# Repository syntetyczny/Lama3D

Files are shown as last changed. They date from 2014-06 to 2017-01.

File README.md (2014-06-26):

Lama3D
======

Fullmetal hotend

Project and all files attached are licensed by Creative Commons license CC BY-SA 3.0 . If you want to comercially use project contact the author:
Paweł Janusz Dobrowolski
email: pawel.j.dobrowolski@gmail.com
company email: pjd@pjd-automatyka.pl

legal links:
http://creativecommons.org/licenses/by-sa/3.0/

http://creativecommons.org/licenses/by-sa/3.0/pl/legalcode

http://creativecommons.org/licenses/by-sa/3.0/pl/

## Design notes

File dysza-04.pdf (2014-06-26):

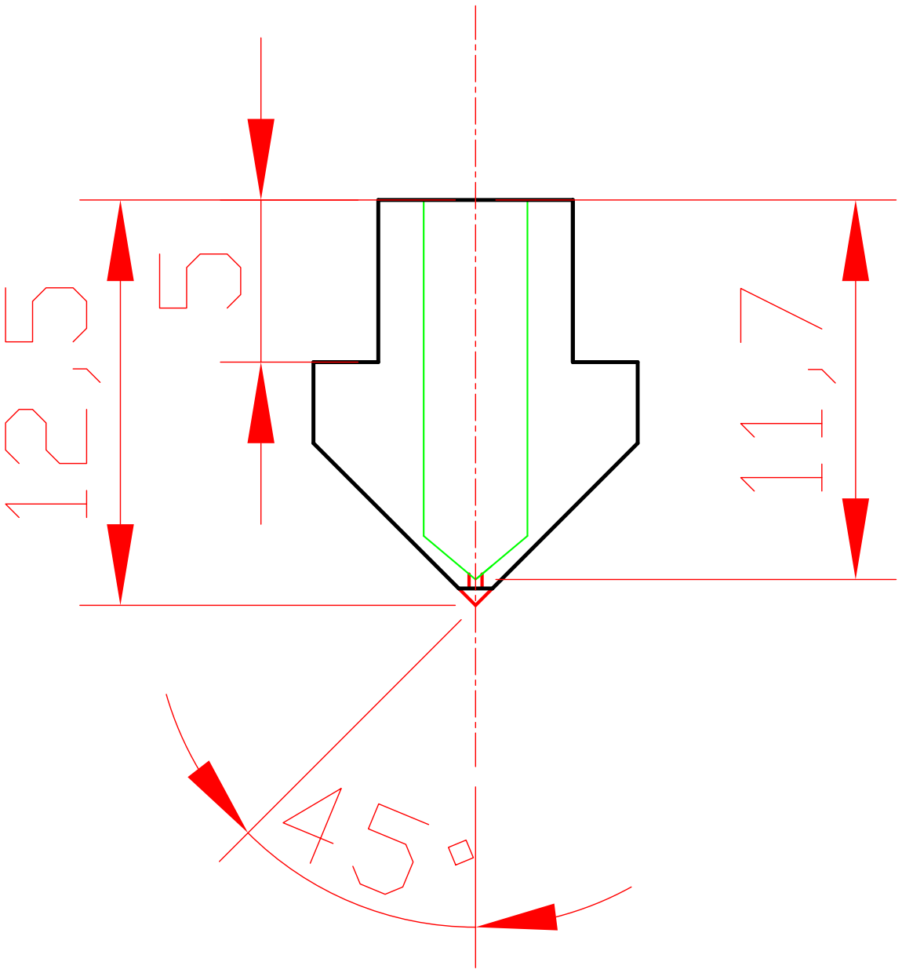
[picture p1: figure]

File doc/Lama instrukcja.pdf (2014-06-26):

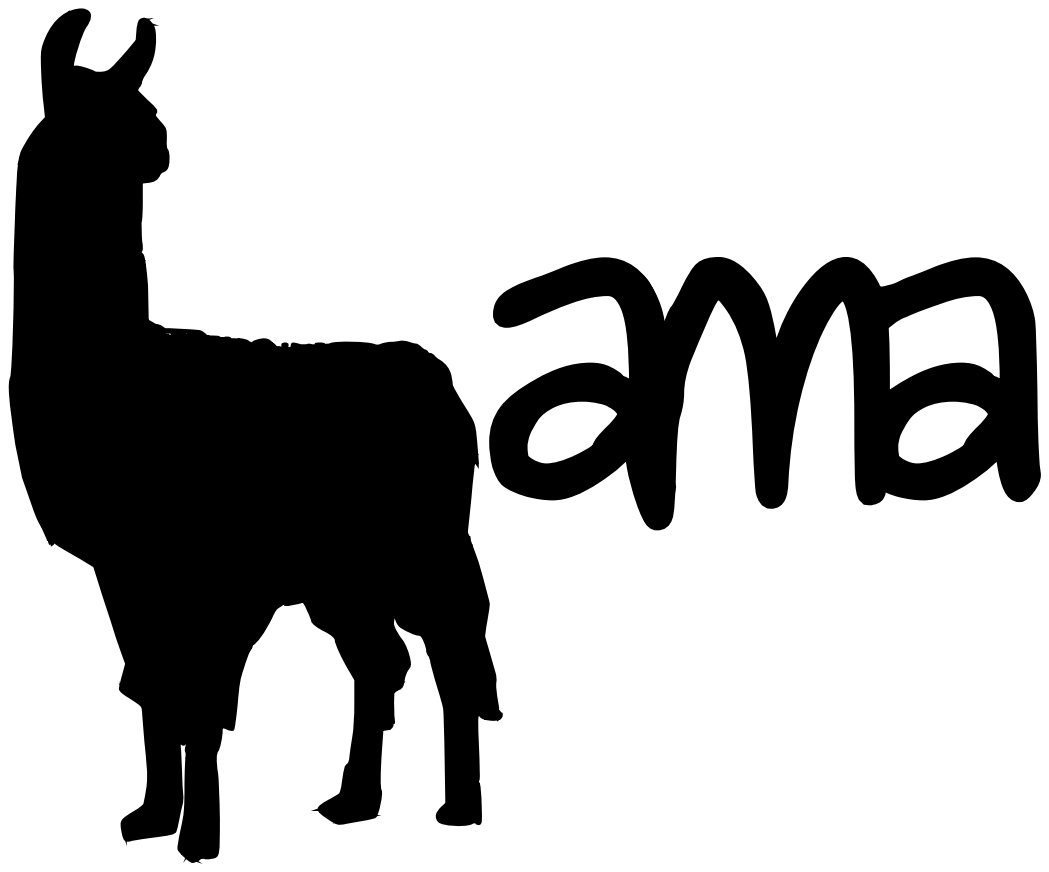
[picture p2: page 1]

Zestaw Lama3D zawiera:

- dyszę 0.4/0.5 mm
- stalowy łącznik nierdzewny
- aluminiowy blok grzejny
- aluminiowy radiator fi25
- Plastikowy uchwyt na wentylator
- Wentylator 40mm
- Koszulka silikonowo-szklana izolacyjna na termistor

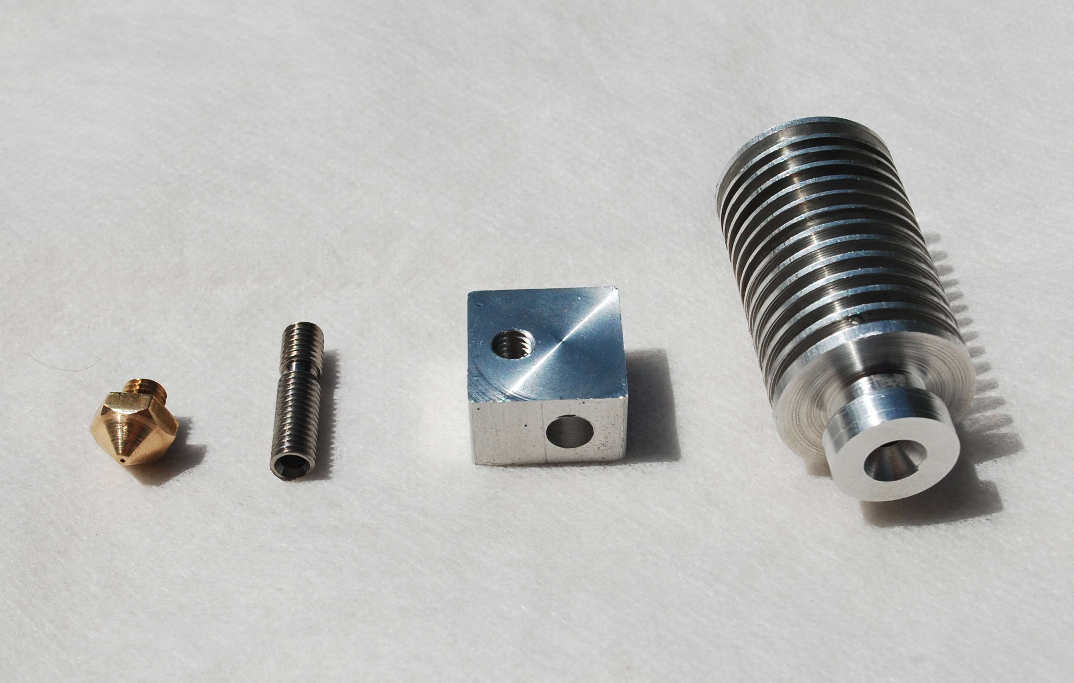
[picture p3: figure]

Dyszę wkręć w blok aluminiowy do napotkania oporu.

Łącznik stalowy wkręć z drugiej strony bloku.

Kiedy napotkasz opór odkręć o ¼ obrotu dyszę i dokręć łącznik do końca. Powinno to umożliwić późniejsze dokręcenie dyszy, w celu zapobiegnięcia wycieków.

Minimalny odstęp jaki powinien być widoczny pomiędzy dyszą a blokiem aluminiowym jest zaznaczony dużą zieloną strzałką.

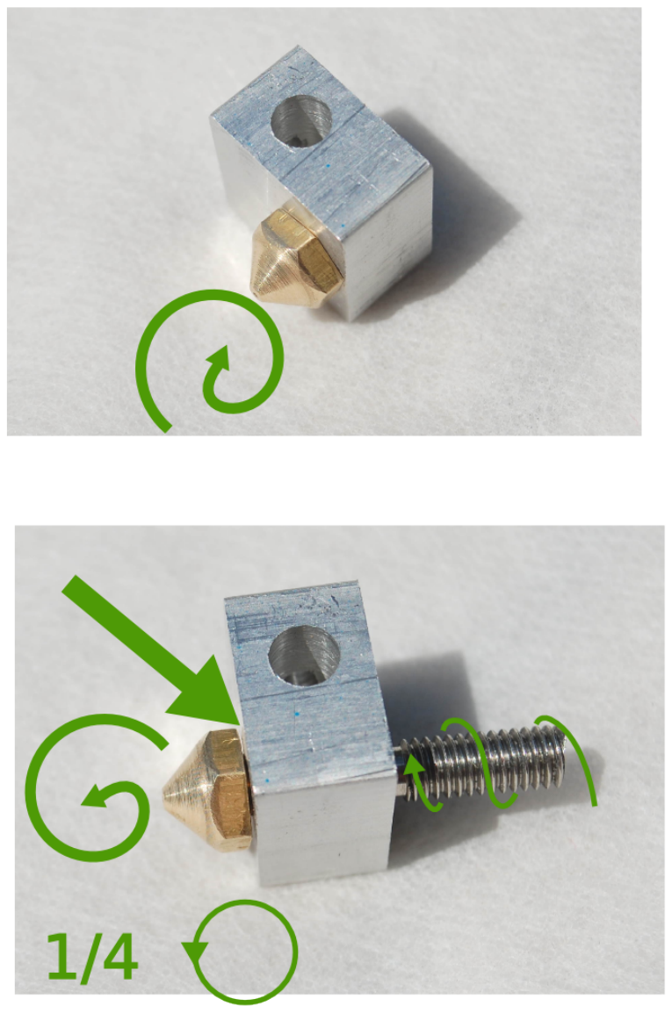
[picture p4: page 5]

Do całości dokręć teraz radiator tak aby odstęp pomiędzy nim a blokiem miał około 2mm.

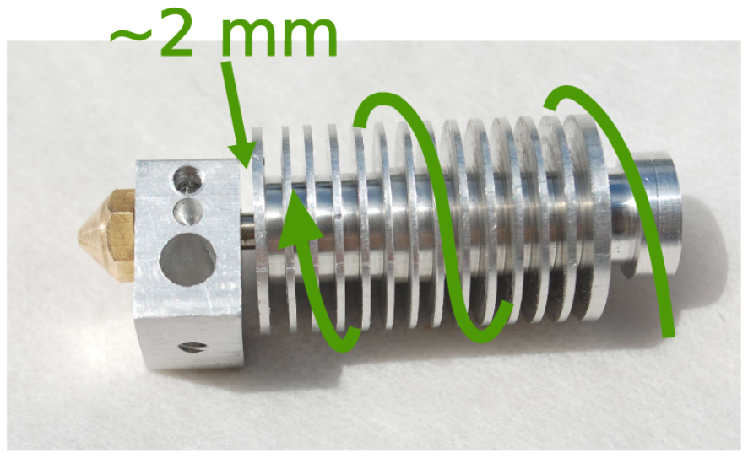
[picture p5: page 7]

Montaż termistora i grzałki

Nasuń osłonki na termistor jak pokazano na ilustracji.

Przygotuj:

- złożony zestaw dysza + radiator
- termistor w izolacji silikonowo-szklanej
- pastę termoprzewodzącą
- śrubkę M4L10 wraz z podkładką

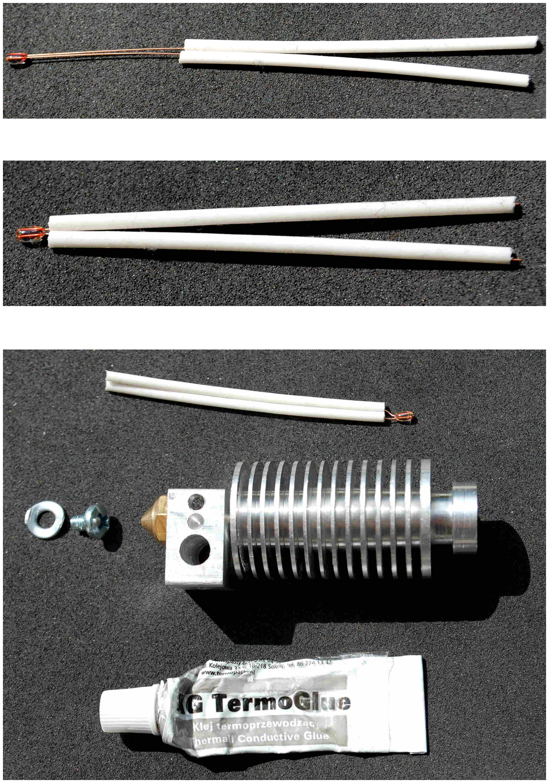
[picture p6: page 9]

Środkowy (niegwintowany) otwór na bloczku aluminiowym wypełnij pastą termoprzewodzącą po czym wsuń w niego termistor.

Dokręć całość śrubką M4L10 wraz z podkładką jak pokazano na ilustracji tym samym przymocowując termistor do bloku.

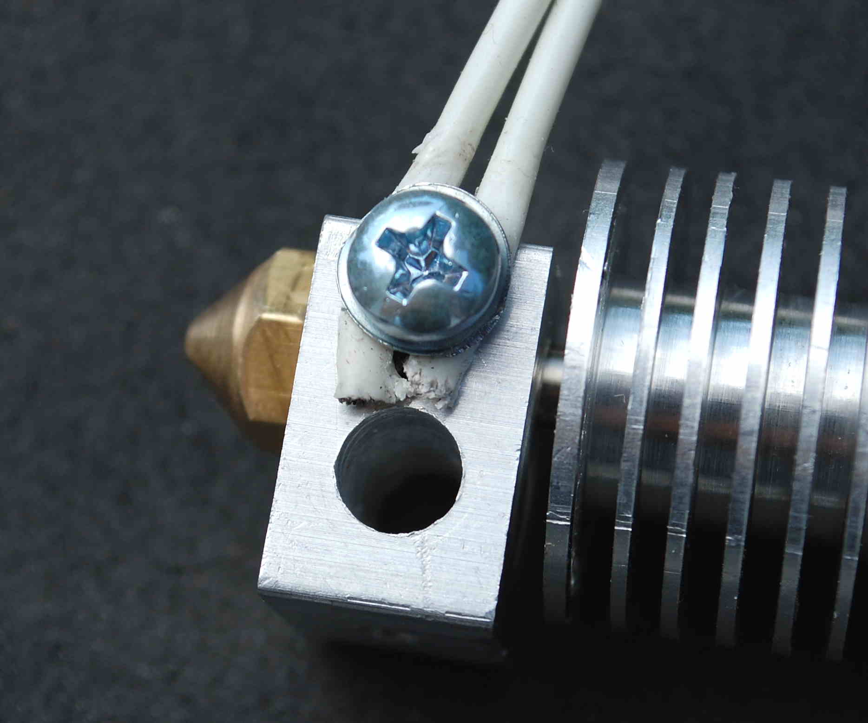
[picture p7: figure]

Przygotuj:
- elementy złożone w poprzednich krokach
- grzałkę
- śrubkę typu robaczek M4L4

Przełóż grzałkę przez najszerszy otwór w bloku po czym dokręć ją z boku robaczkiem M4L4.

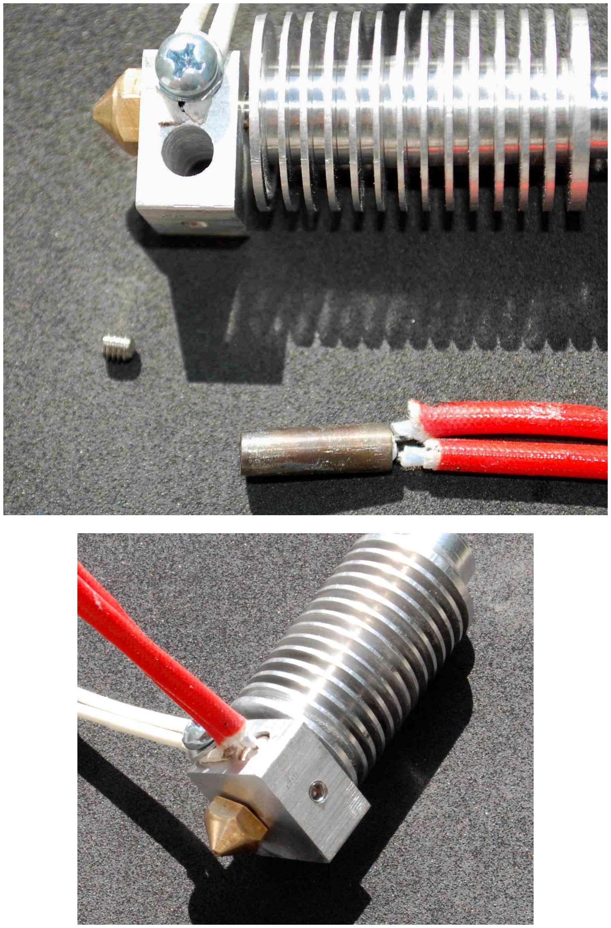
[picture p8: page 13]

Tak przygotowaną głowicę, montujemy do drukarki i nagrzewamy do temperatury 250st C. Następnie przygotowujemy 2 klucze płaskie -20(zamiast tego, może być użyty klucz uniwersalny) oraz 10. Kiedy głowica osiągnie 250st C, chwytamy kluczem 20 blok grzejny, oraz kluczem 10 dyszę i dokręcamy delikatnie dyszę do łącznika, aż poczujemy opór. Następnie używając już tylko klucza 10, dokręcamy całość do radiatora. Obie te operacje mają zapobiec wyciekowi roztopionego materiału na łączeniu dysza-łącznik oraz usunięcia luzu na połączeniu łącznik-radiator.

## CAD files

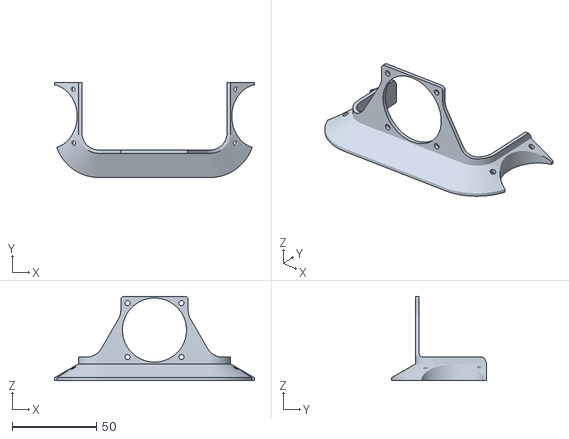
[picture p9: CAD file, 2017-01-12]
stl/BYQvent.stl
118.6 x 56.3 x 50.0

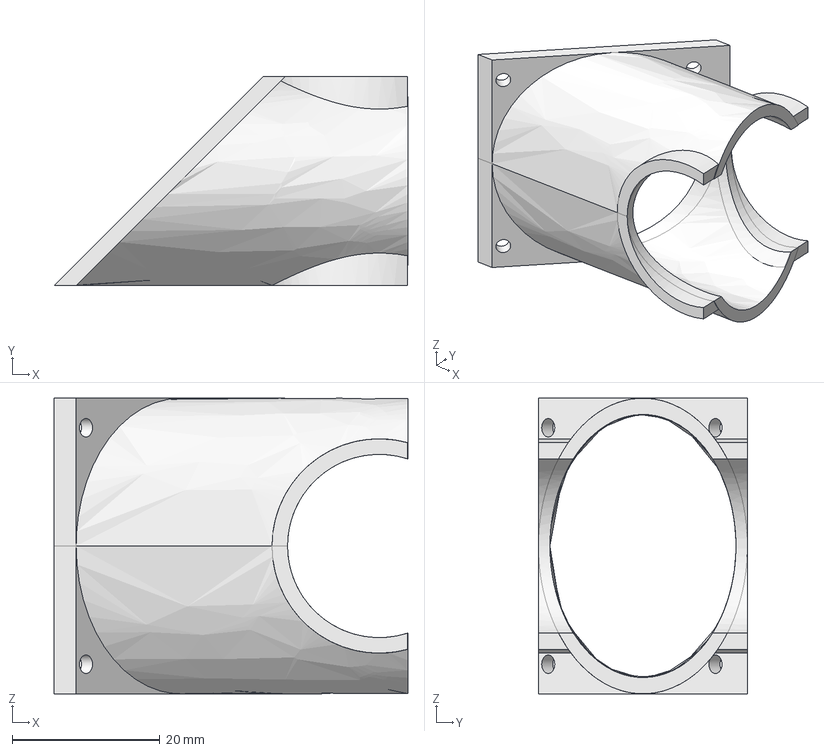
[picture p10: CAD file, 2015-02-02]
stl/uchwyt-wentylator-Mendel-thiner.fcstd
47.9 x 28.3 x 40.0 mm

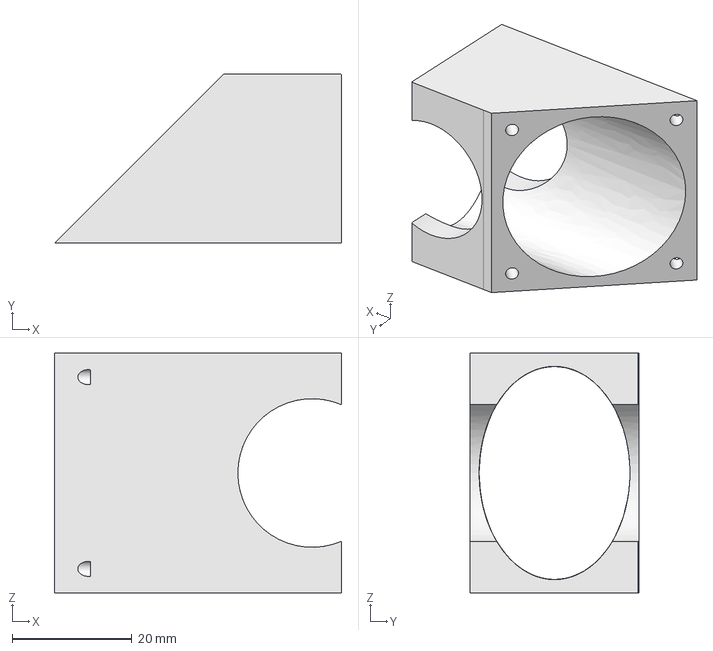
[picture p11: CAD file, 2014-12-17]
stl/uchwyt-wentylator-Mendel.fcstd
47.9 x 28.3 x 40.0 mm

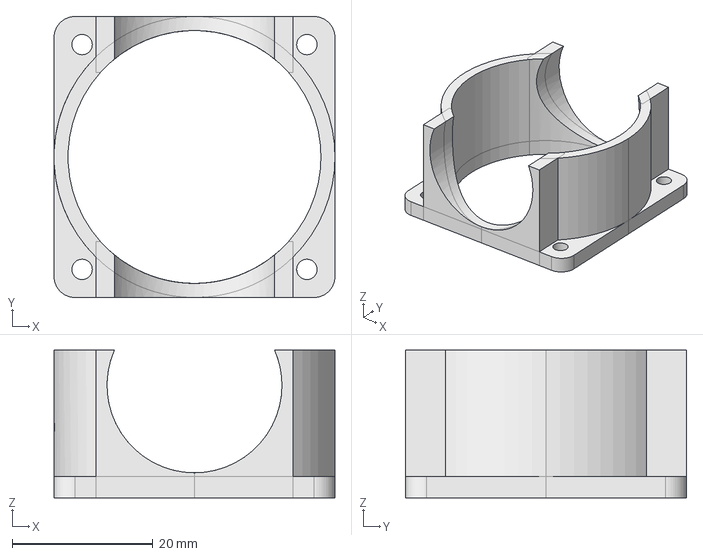
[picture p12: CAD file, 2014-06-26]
stl/wentyl v5 fi25.fcstd
40.0 x 40.0 x 21.0 mm

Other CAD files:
stl/uchwyt-wentylator-Mendel-thiner.stl
stl/uchwyt-wentylator-Mendel.stl
stl/wentyl v5 fi25.stl

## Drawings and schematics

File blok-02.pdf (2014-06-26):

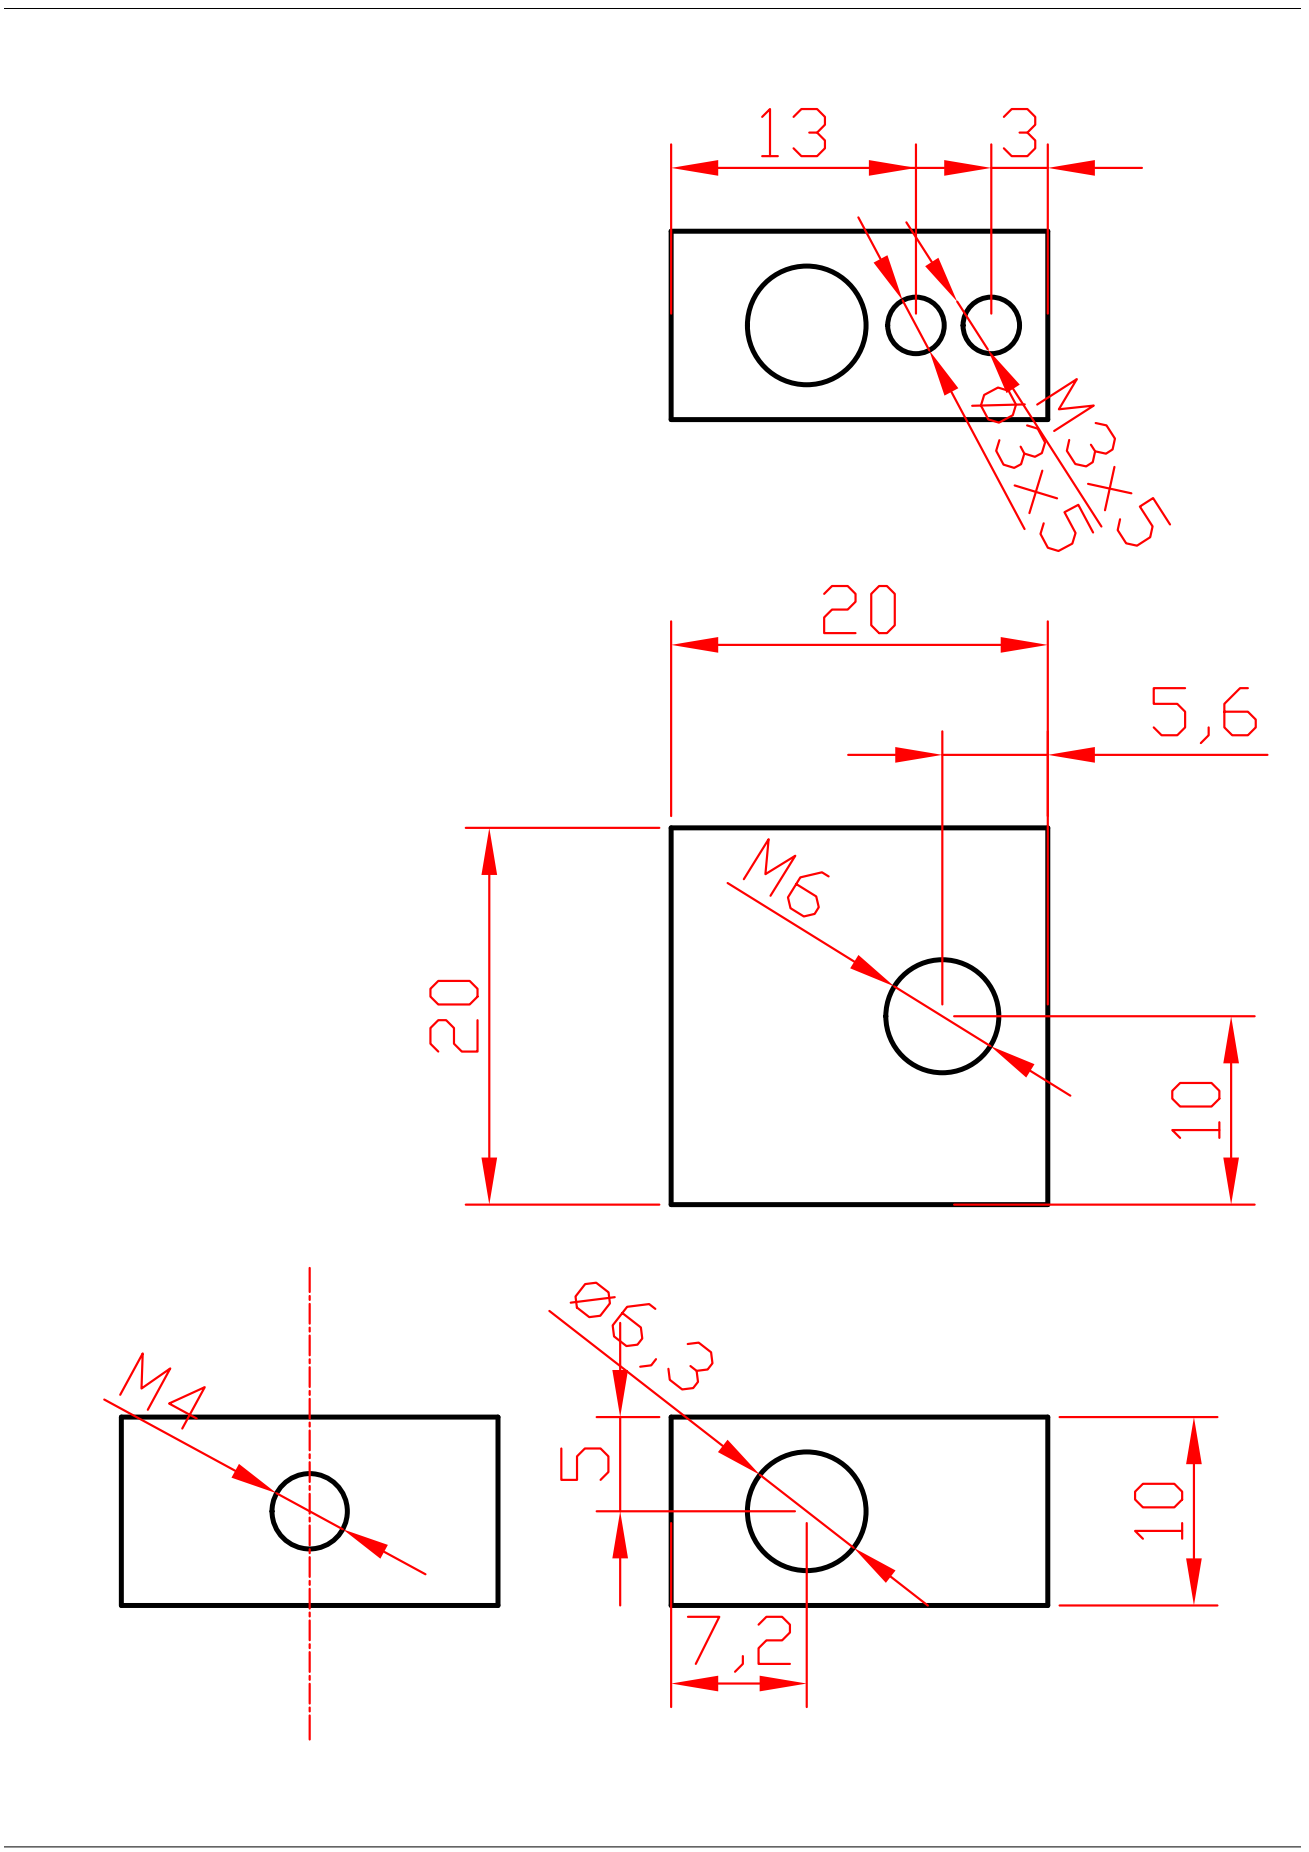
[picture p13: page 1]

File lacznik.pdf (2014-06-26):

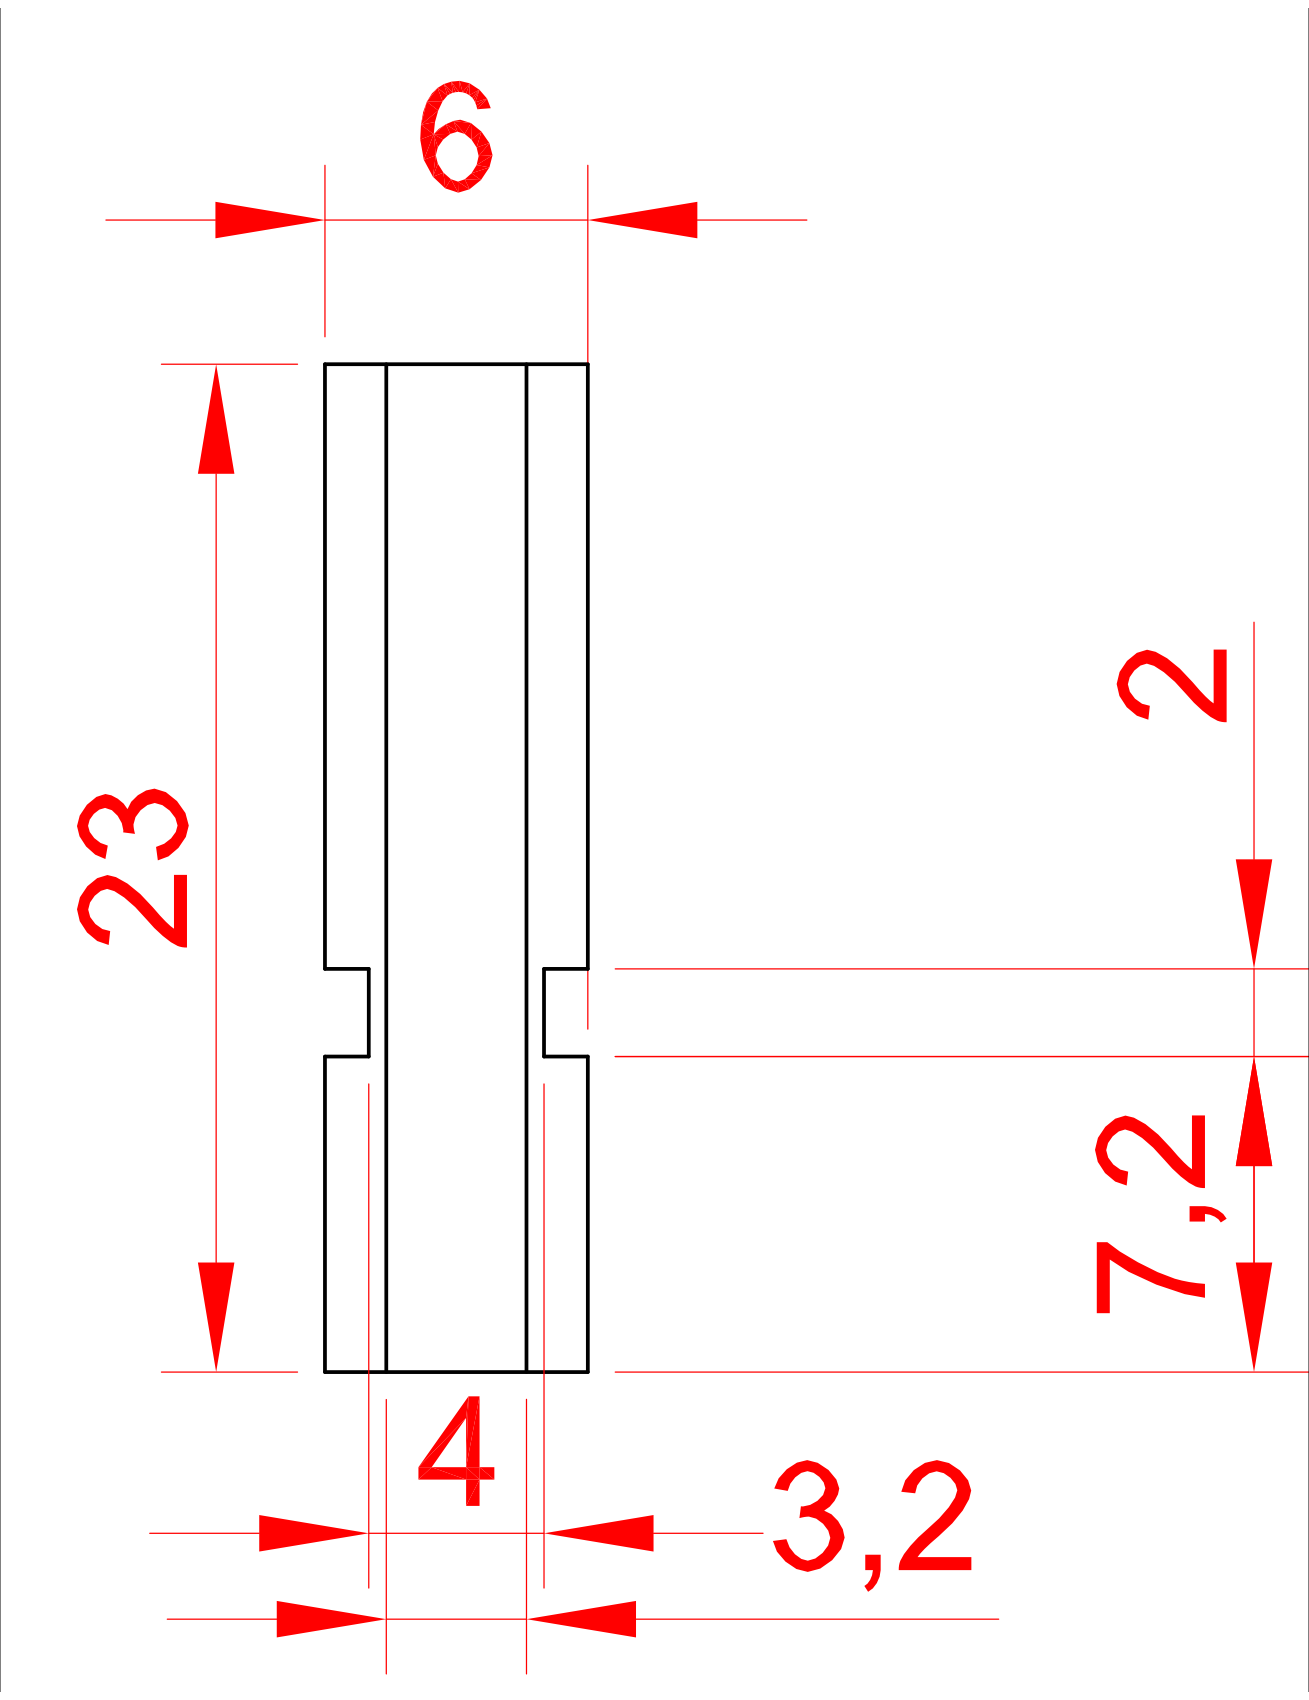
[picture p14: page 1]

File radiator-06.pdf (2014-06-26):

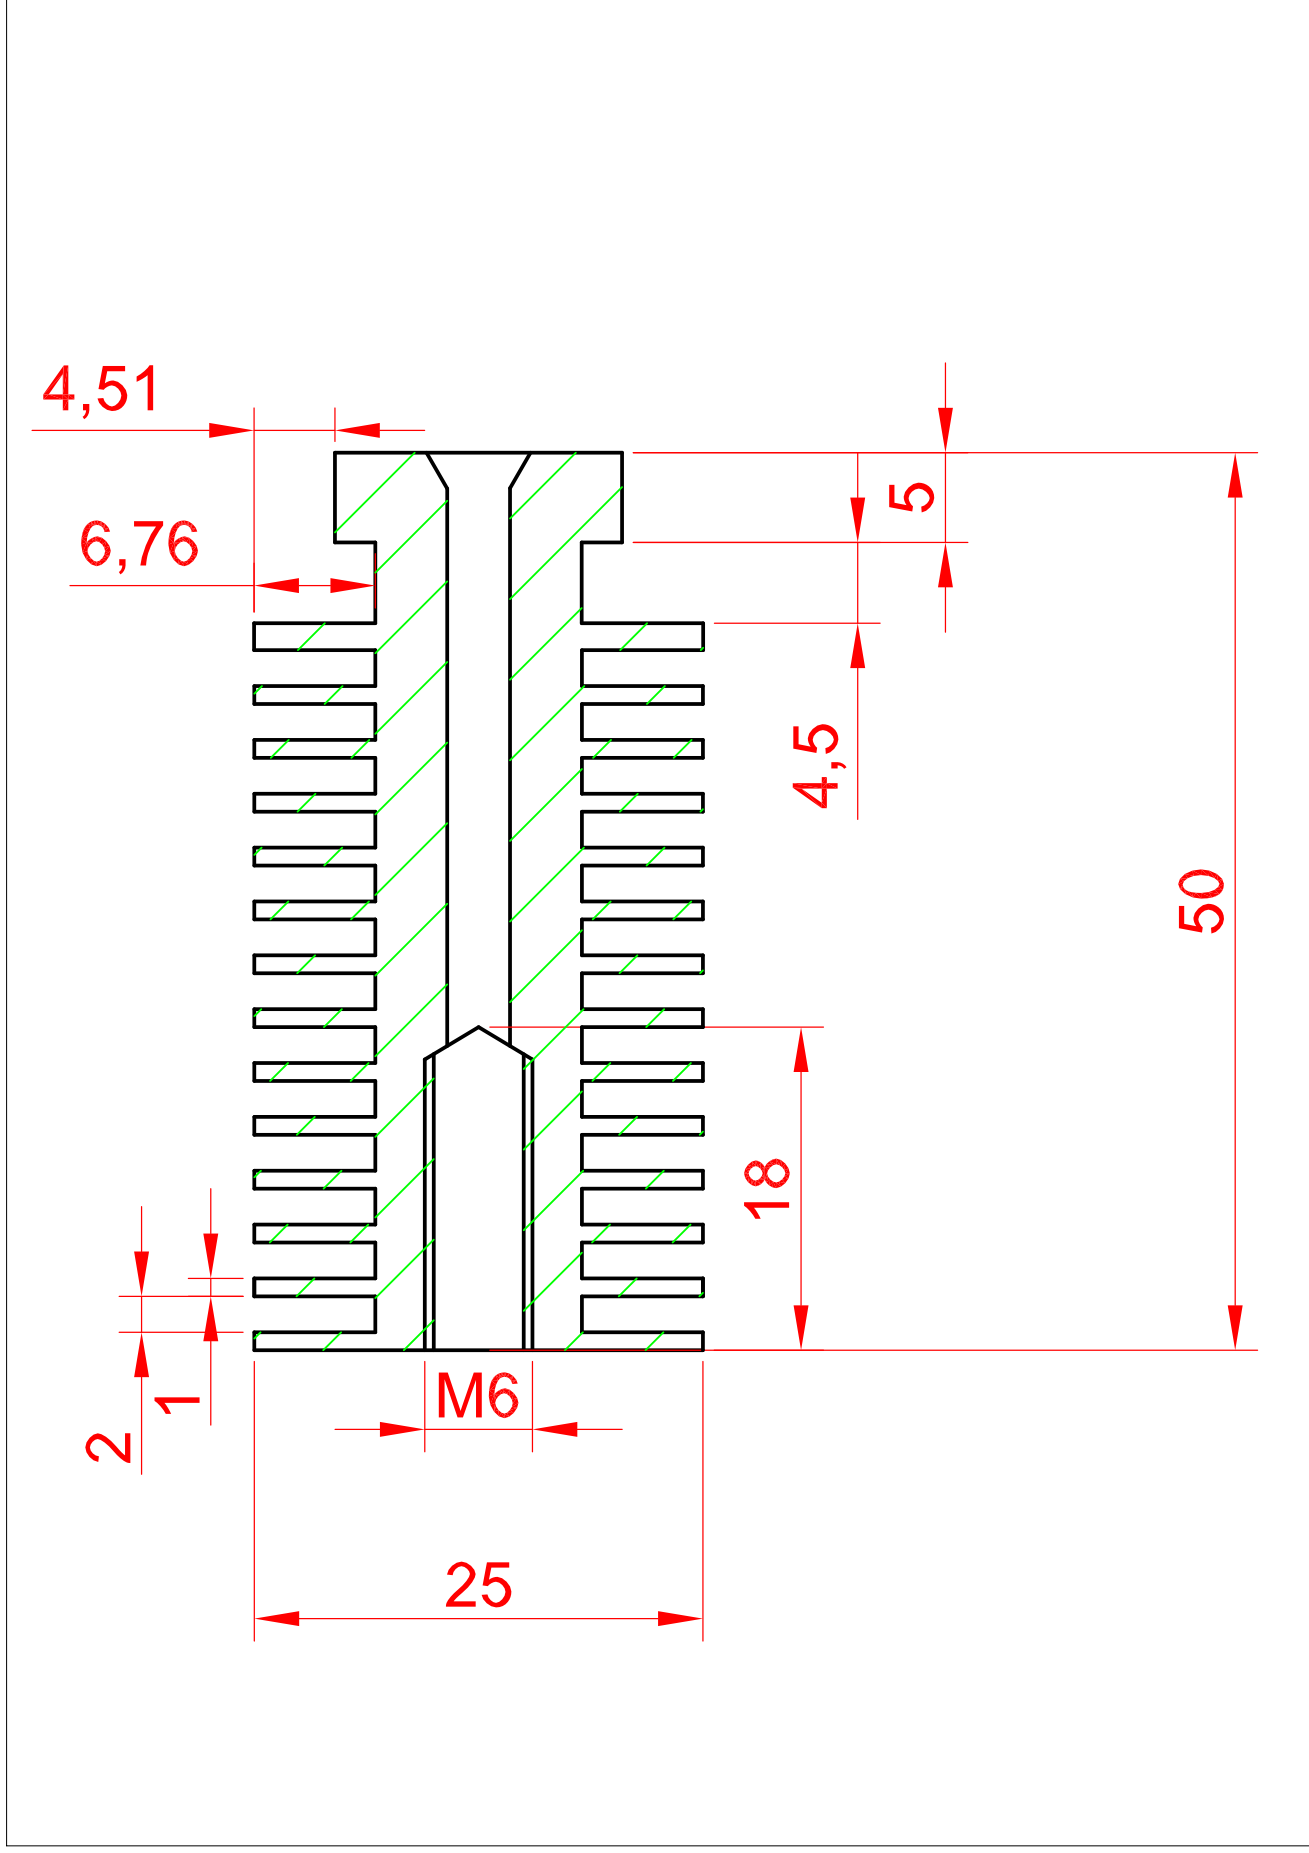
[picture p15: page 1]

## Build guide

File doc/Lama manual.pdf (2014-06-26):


Lama3D set includes:

- 0.4/0.5 mm nozzle
- stainless steel heat breaker
- aluminium heating block
- aluminium radiator fi25
- Plastic fan holder
- 40mm fan
- silicon-glass insulator for thermistor


Screw the nozzle in until resistance is is encountered.

Screw the stainless steel connector in from the opposite side.

When resistance is encountered unscrew the nozzle by ¼ of a circle and drive in the connector. This should allow for driving in the nozzle later.

Minimal distance between the block and the nozzle is marked with the green arrow.


Nut the radiator onto the connector so that the space between it and the aluminium block is about 2mm.


Thermistor and heater installation

Put on the insulating tubes like shown in the pictures.

Prepare:

- completed set from previous steps
- thermistor in it's silicon-glass insulation
- thermal conductive glue
- M4L10 screw with washer


Fill the middle hole on the block with thermal conducting glue and put in the thermistor.

Using the M4L10 screw and the washer immobilize the thermistor like shown in the picture.


Prepare:
- elements built in previous steps
- heater
- tiny M4L4 screw

Put the heater through the biggest hole in the block and fix it with the M4L4 screw.


When the hotend has been prepared install it in the printer and heat up to 250 degrees Celsius.
Prepare two wrenches - 20mm and 10mm. When the heating block reaches 250 degrees grab the heating block with the 20mm wrench and use the 10mm one to screw in the nozzle until you encounter resistance. Next, using only the 10 mm wrench fix the nozzle-block-connector section to the radiator.
Those operations are supposed to prevent leaks and eliminate clearance between connector and the radiator.

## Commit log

2014-06-26 Added stl
    [wentyl v5 fi25.fcstd, wentyl v5 fi25.stl]
2014-12-17 Mendel Fan holder
    [wentyl (repaired).stl]
2014-12-17 Mendel Fan holder source
    [uchwyt-wentylator-Mendel.fcstd]
2014-12-17 Changed name
    [uchwyt-wentylator.Mendel.stl]
2015-02-02 Adding new fan holder
    [uchwyt-wentylator-Mendel-thiner.fcstd, uchwyt-wentylator-Mendel-thiner.stl]
2017-01-12 Add BYQVent stl
    [BYQvent.stl]
